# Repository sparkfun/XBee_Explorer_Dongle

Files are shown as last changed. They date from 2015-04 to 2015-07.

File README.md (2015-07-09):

SparkFun XBee Explorer Dongle
========================================

SparkFun XBee Explorer Dongle

[*SparkFun XBee Explorer Dongle (WRL-11697)*](https://www.sparkfun.com/products/11697)

With the XBee Explorer Dongle you can plug the unit directly into your USB port 
and have it act as a gateway between your computer and the XBee. It has the FT231X USB-to-serial converter IC on board. 

Repository Contents
-------------------
* **/Hardware** - All Eagle design files (.brd, .sch, .STL)
* **/Production** - Test bed files and production panel files

Documentation
--------------
* **[Hookup Guide](https://learn.sparkfun.com/tutorials/exploring-xbees-and-xctu)** - Basic hookup guide for the XBee Explorer.
* **[SparkFun Fritzing repo](https://github.com/sparkfun/Fritzing_Parts)** - Fritzing diagrams for SparkFun products.
* **[SparkFun 3D Model repo](https://github.com/sparkfun/3D_Models)** - 3D models of SparkFun products. 

Product Versions
----------------
* [WRL-11697](https://www.sparkfun.com/products/11697)- XBee Dongle with the FT232 USB to serial converter, v23. Current.
* [WRL-09819](https://www.sparkfun.com/products/retired/9819)- XBee Dongle with the FT232 USB to serial converter, v12. Retired.

Version History
---------------
* [V_2.3](https://github.com/sparkfun/XBee_Explorer_Dongle/tree/V_2.3) - GitHub files, version 2.3. Current
* [V_2.2](https://github.com/sparkfun/XBee_Explorer_Dongle/tree/V_2.2) - GitHub files, version 2.2
* [V_1.2](https://github.com/sparkfun/XBee_Explorer_Dongle/tree/V_1.2) -GitHub files, version 1.2. 

License Information
-------------------

This product is _**open source**_! 

Please review the LICENSE.md file for license information. 

If you have any questions or concerns on licensing, please contact techsupport@sparkfun.com.

Distributed as-is; no warranty is given.

- Your friends at SparkFun.

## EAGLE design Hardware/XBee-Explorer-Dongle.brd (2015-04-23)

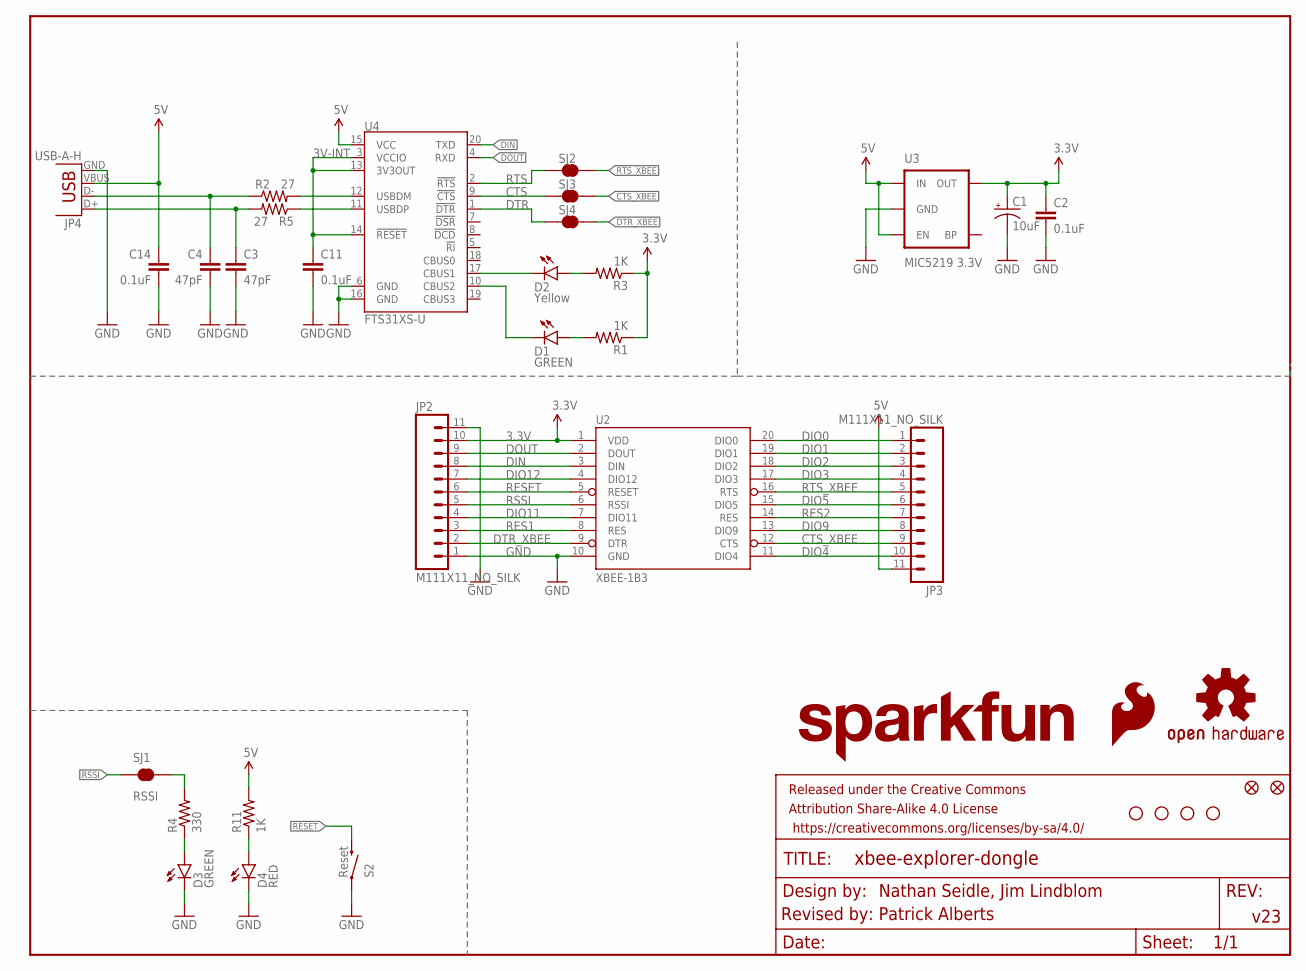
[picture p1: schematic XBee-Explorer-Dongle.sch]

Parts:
C1: 10uF; EIA3216
C2, C11, C14: 0.1uF; 0603-CAP
C3, C4: 47pF; 0603-CAP
D1, D3: GREEN; LED-0603
D2: Yellow; LED-0603
D4: RED; LED-0603
FID1, FID2: FIDUCIAL1X2; FIDUCIAL-1X2
FRAME1: FRAME-LETTER; CREATIVE_COMMONS
JP2, JP3: M111X11_NO_SILK; 1X11_NO_SILK
JP4: USB-A-H
LOGO1: SFE_LOGO_FLAME.1_INCH; SFE_LOGO_FLAME_.1
LOGO2: SFE_LOGO_NAME.2_INCH; SFE_LOGO_NAME_.2
R1, R3, R11: 1K; 0603-RES
R2, R5: 27; 0603-RES
R4: 330; 0603-RES
S2: Reset; TACTILE_SWITCH_SMD
SJ1, SJ2, SJ3, SJ4: RSSI; SJ_2S-TRACE
U2: XBEE-1B3; XBEE-SMD
U3: MIC5219 3.3V; SOT23-5
U4: FTS31XS-U; SSOP20_L
U$5, U$9, U$10, U$11: STAND-OFF
U$7: OSHW-LOGOS; OSHW-LOGO-S

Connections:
3.3V: C1.A (+), C2.1, JP2.10, R1.1, R3.1, U2.1 (VDD), U3.5 (OUT)
3V-INT: C11.1, U4.3 (VCCIO), U4.13 (3V3OUT), U4.14 (!RESET)
5V: C14.1, JP3.11, JP4.VBUS, R11.2, U3.1 (IN), U3.3 (EN), U4.15 (VCC)
CTS: SJ3.1, U4.9 (!CTS)
CTS_XBEE: JP3.9, SJ3.2, U2.12 (CTS)
DIN: JP2.8, U2.3 (DIN), U4.20 (TXD)
DIO0: JP3.1, U2.20 (DIO0)
DIO1: JP3.2, U2.19 (DIO1)
DIO2: JP3.3, U2.18 (DIO2)
DIO3: JP3.4, U2.17 (DIO3)
DIO4: JP3.10, U2.11 (DIO4)
DIO5: JP3.6, U2.15 (DIO5)
DIO9: JP3.8, U2.13 (DIO9)
DIO11: JP2.4, U2.7 (DIO11)
DIO12: JP2.7, U2.4 (DIO12)
DOUT: JP2.9, U2.2 (DOUT), U4.4 (RXD)
DTR: SJ4.1, U4.1 (!DTR)
DTR_XBEE: JP2.2, SJ4.2, U2.9 (DTR)
GND: C1.C (-), C2.2, C3.2, C4.2, C11.2, C14.2, D3.C, D4.C, JP2.1, JP2.11, JP4.GND, S2.1, U2.10 (GND), U3.2 (GND), U4.6 (GND), U4.16 (GND)
unnamed: D1.A, R1.2
unnamed: D3.A, R4.1
unnamed: C4.1, JP4.D-, R2.1
unnamed: D2.A, R3.2
unnamed: R2.2, U4.12 (USBDM)
unnamed: C3.1, JP4.D+, R5.2
unnamed: R5.1, U4.11 (USBDP)
unnamed: R4.2, SJ1.2
unnamed: D4.A, R11.1
RES1: JP2.3, U2.8 (RES)
RES2: JP3.7, U2.14 (RES)
RESET: JP2.6, S2.3 (2), U2.5 (RESET)
RSSI: JP2.5, SJ1.1, U2.6 (RSSI)
RTS: SJ2.1, U4.2 (!RTS)
RTS_XBEE: JP3.5, SJ2.2, U2.16 (RTS)
RXLED: D2.C, U4.17 (CBUS1)
TXLED: D1.C, U4.10 (CBUS2)

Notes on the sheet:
Nathan Seidle, Jim Lindblom
v23
Revised by: Patrick Alberts

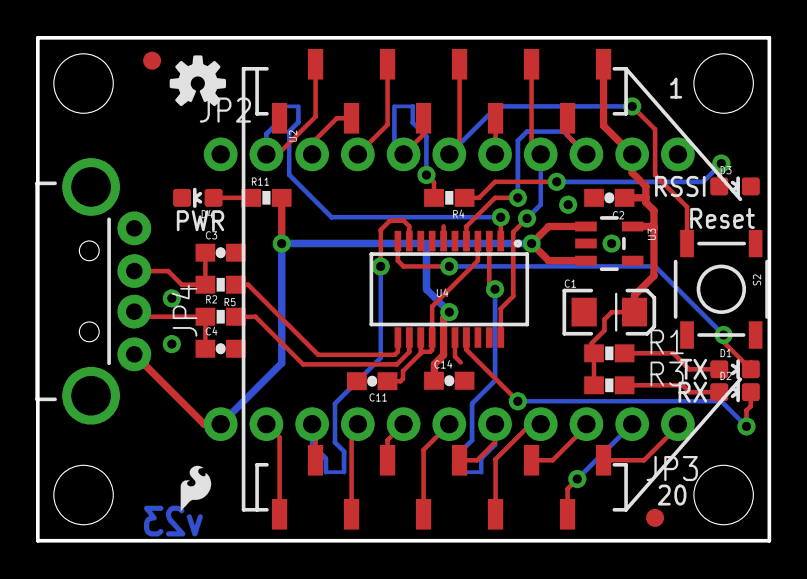
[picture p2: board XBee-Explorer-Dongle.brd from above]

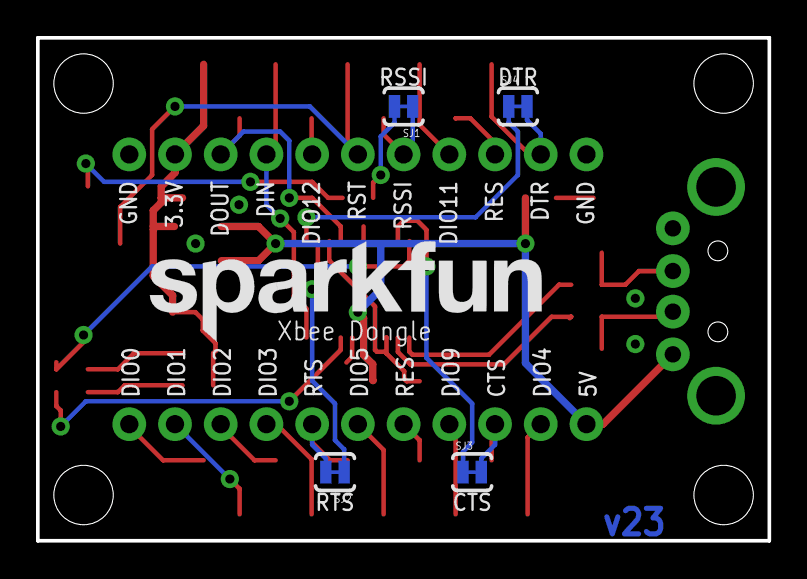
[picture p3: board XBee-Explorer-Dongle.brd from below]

Board: 2 copper layers, 40.6 x 27.9 mm, 37 parts (5 on the bottom side), 36 nets.

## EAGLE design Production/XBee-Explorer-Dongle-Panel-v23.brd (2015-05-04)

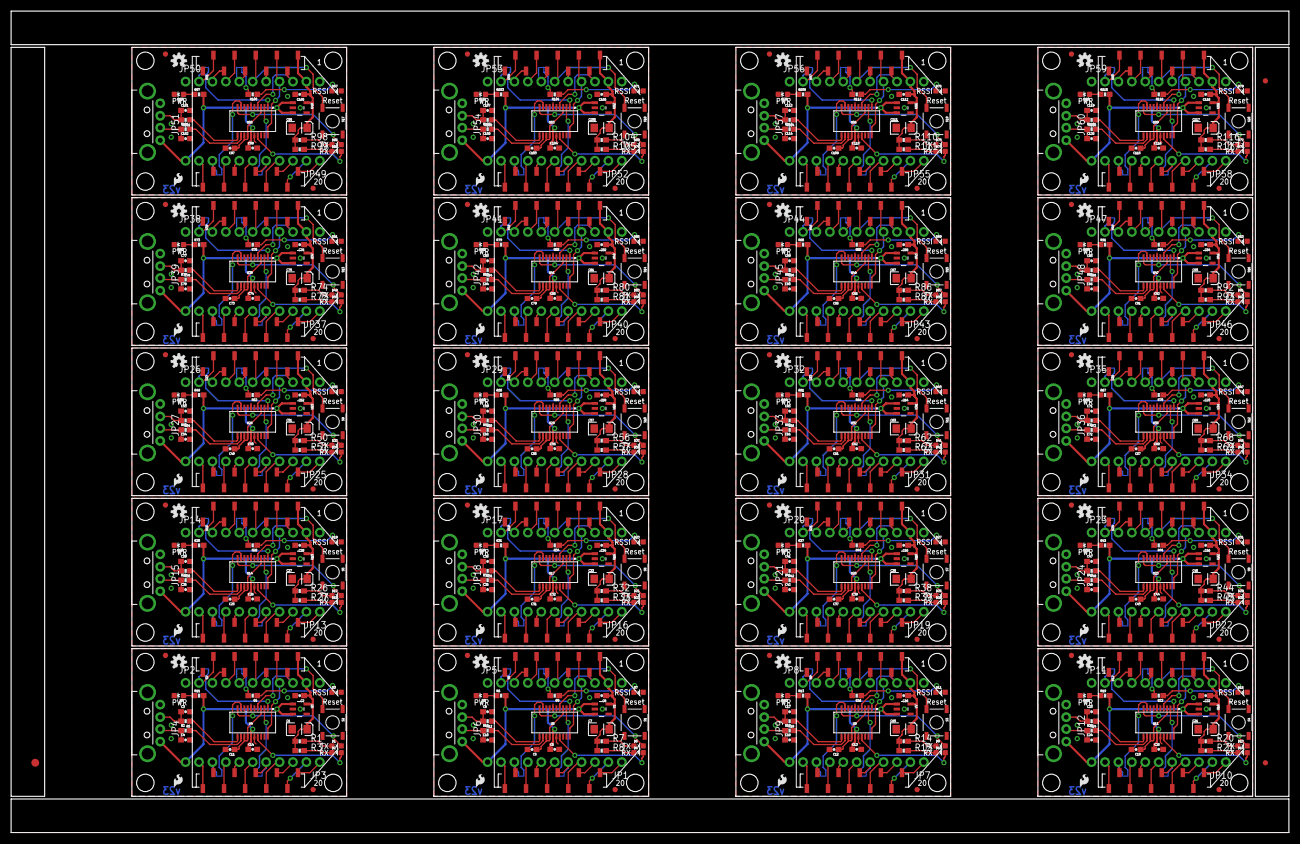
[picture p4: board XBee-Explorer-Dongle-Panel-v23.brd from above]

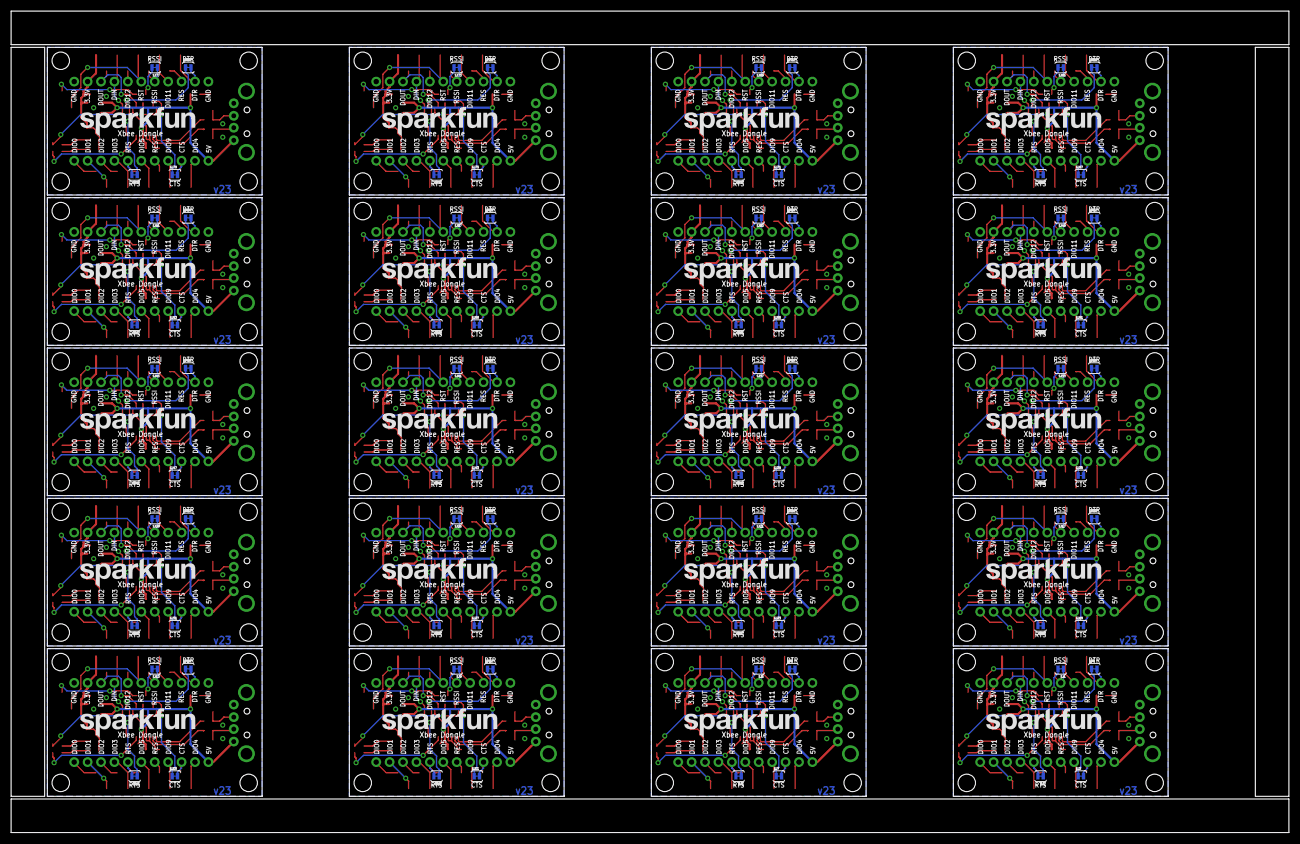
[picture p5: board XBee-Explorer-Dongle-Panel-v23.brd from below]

Board: 2 copper layers, 241.8 x 155.4 mm, 723 parts (100 on the bottom side), 720 nets.

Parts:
C1, C7, C15, C21, C27, C33, C39, C45, C51, C57, C63, C69, C75, C81, C87, C93, C99, C105, C111, C117: 10uF; EIA3216
C2, C5, C6, C8, C11, C12, C13, C14, C16, C19, C20, C22, C25, C26, C28, C31, C32, C34, C37, C38, C40, C43, C44, C46, C49, C50, C52, C55, C56, C58, C61, C62, C64, C67, C68, C70, C73, C74, C76, C79, C80, C82, C85, C86, C88, C91, C92, C94, C97, C98, C100, C103, C104, C106, C109, C110, C112, C115, C116, C118: 0.1uF; 0603-CAP
C3, C4, C9, C10, C17, C18, C23, C24, C29, C30, C35, C36, C41, C42, C47, C48, C53, C54, C59, C60, C65, C66, C71, C72, C77, C78, C83, C84, C89, C90, C95, C96, C101, C102, C107, C108, C113, C114, C119, C120: 47pF; 0603-CAP
D1, D3, D5, D7, D9, D11, D13, D15, D17, D19, D21, D23, D25, D27, D29, D31, D33, D35, D37, D39, D41, D43, D45, D47, D49, D51, D53, D55, D57, D59, D61, D63, D65, D67, D69, D71, D73, D75, D77, D79: GREEN; LED-0603
D2, D6, D10, D14, D18, D22, D26, D30, D34, D38, D42, D46, D50, D54, D58, D62, D66, D70, D74, D78: Yellow; LED-0603
D4, D8, D12, D16, D20, D24, D28, D32, D36, D40, D44, D48, D52, D56, D60, D64, D68, D72, D76, D80: RED; LED-0603
E$1: FIDUCIAL-1.5X3
E$5, E$6: FIDUCIAL-1X2
FID1, FID2, FID3, FID4, FID5, FID6, FID7, FID8, FID9, FID10, FID11, FID12, FID13, FID14, FID15, FID16, FID17, FID18, FID19, FID20, FID21, FID22, FID23, FID24, FID25, FID26, FID27, FID28, FID29, FID30, FID31, FID32, FID33, FID34, FID35, FID36, FID37, FID38, FID39, FID40: FIDUCIAL1X2; FIDUCIAL-1X2
JP1, JP2, JP3, JP5, JP7, JP8, JP10, JP11, JP13, JP14, JP16, JP17, JP19, JP20, JP22, JP23, JP25, JP26, JP28, JP29, JP31, JP32, JP34, JP35, JP37, JP38, JP40, JP41, JP43, JP44, JP46, JP47, JP49, JP50, JP52, JP53, JP55, JP56, JP58, JP59: M111X11_NO_SILK; 1X11_NO_SILK
JP4, JP6, JP9, JP12, JP15, JP18, JP21, JP24, JP27, JP30, JP33, JP36, JP39, JP42, JP45, JP48, JP51, JP54, JP57, JP60: USB-A-H
LOGO1, LOGO3, LOGO5, LOGO7, LOGO9, LOGO11, LOGO13, LOGO15, LOGO17, LOGO19, LOGO21, LOGO23, LOGO25, LOGO27, LOGO29, LOGO31, LOGO33, LOGO35, LOGO37, LOGO39: SFE_LOGO_FLAME.1_INCH; SFE_LOGO_FLAME_.1
LOGO2, LOGO4, LOGO6, LOGO8, LOGO10, LOGO12, LOGO14, LOGO16, LOGO18, LOGO20, LOGO22, LOGO24, LOGO26, LOGO28, LOGO30, LOGO32, LOGO34, LOGO36, LOGO38, LOGO40: SFE_LOGO_NAME.2_INCH; SFE_LOGO_NAME_.2
R1, R3, R6, R7, R8, R11, R13, R14, R15, R19, R20, R21, R25, R26, R27, R31, R32, R33, R37, R38, R39, R43, R44, R45, R49, R50, R51, R55, R56, R57, R61, R62, R63, R67, R68, R69, R73, R74, R75, R79, R80, R81, R85, R86, R87, R91, R92, R93, R97, R98, R99, R103, R104, R105, R109, R110, R111, R115, R116, R117: 1K; 0603-RES
R2, R5, R10, R12, R17, R18, R23, R24, R29, R30, R35, R36, R41, R42, R47, R48, R53, R54, R59, R60, R65, R66, R71, R72, R77, R78, R83, R84, R89, R90, R95, R96, R101, R102, R107, R108, R113, R114, R119, R120: 27; 0603-RES
R4, R9, R16, R22, R28, R34, R40, R46, R52, R58, R64, R70, R76, R82, R88, R94, R100, R106, R112, R118: 330; 0603-RES
S1, S2, S3, S4, S5, S6, S7, S8, S9, S10, S11, S12, S13, S14, S15, S16, S17, S18, S19, S20: Reset; TACTILE_SWITCH_SMD
SJ1, SJ2, SJ3, SJ4, SJ5, SJ6, SJ7, SJ8, SJ9, SJ10, SJ11, SJ12, SJ13, SJ14, SJ15, SJ16, SJ17, SJ18, SJ19, SJ20, SJ21, SJ22, SJ23, SJ24, SJ25, SJ26, SJ27, SJ28, SJ29, SJ30, SJ31, SJ32, SJ33, SJ34, SJ35, SJ36, SJ37, SJ38, SJ39, SJ40, SJ41, SJ42, SJ43, SJ44, SJ45, SJ46, SJ47, SJ48, SJ49, SJ50, SJ51, SJ52, SJ53, SJ54, SJ55, SJ56, SJ57, SJ58, SJ59, SJ60, SJ61, SJ62, SJ63, SJ64, SJ65, SJ66, SJ67, SJ68, SJ69, SJ70, SJ71, SJ72, SJ73, SJ74, SJ75, SJ76, SJ77, SJ78, SJ79, SJ80: RSSI; SJ_2S-TRACE
U1, U3, U7, U10, U13, U16, U19, U22, U25, U28, U31, U34, U37, U40, U43, U46, U49, U52, U55, U58: MIC5219 3.3V; SOT23-5
U2, U6, U9, U12, U15, U18, U21, U24, U27, U30, U33, U36, U39, U42, U45, U48, U51, U54, U57, U60: XBEE-1B3; XBEE-SMD
U4, U5, U8, U11, U14, U17, U20, U23, U26, U29, U32, U35, U38, U41, U44, U47, U50, U53, U56, U59: FTS31XS-U; SSOP20_L
U$1, U$2, U$3, U$4, U$5, U$8, U$9, U$10, U$11, U$12, U$13, U$14, U$16, U$17, U$18, U$19, U$21, U$22, U$23, U$24, U$26, U$27, U$28, U$29, U$31, U$32, U$33, U$34, U$36, U$37, U$38, U$39, U$41, U$42, U$43, U$44, U$46, U$47, U$48, U$49, U$51, U$52, U$53, U$54, U$56, U$57, U$58, U$59, U$61, U$62, U$63, U$64, U$66, U$67, U$68, U$69, U$71, U$72, U$73, U$74, U$76, U$77, U$78, U$79, U$81, U$82, U$83, U$84, U$86, U$87, U$88, U$89, U$91, U$92, U$93, U$94, U$96, U$97, U$98, U$99: STAND-OFF
U$6, U$7, U$15, U$20, U$25, U$30, U$35, U$40, U$45, U$50, U$55, U$60, U$65, U$70, U$75, U$80, U$85, U$90, U$95, U$100: OSHW-LOGOS; OSHW-LOGO-S

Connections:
3.3V: C1.A, C2.1, JP2.10, R1.1, R3.1, U2.1, U3.5
3.3V1: C7.A, C8.1, JP5.10, R7.1, R8.1, U1.5, U6.1
3.3V2: C15.A, C16.1, JP8.10, R14.1, R15.1, U7.5, U9.1
3.3V3: C21.A, C22.1, JP11.10, R20.1, R21.1, U10.5, U12.1
3.3V4: C27.A, C28.1, JP14.10, R26.1, R27.1, U13.5, U15.1
3.3V5: C33.A, C34.1, JP17.10, R32.1, R33.1, U16.5, U18.1
3.3V6: C39.A, C40.1, JP20.10, R38.1, R39.1, U19.5, U21.1
3.3V7: C45.A, C46.1, JP23.10, R44.1, R45.1, U22.5, U24.1
3.3V8: C51.A, C52.1, JP26.10, R50.1, R51.1, U25.5, U27.1
3.3V9: C57.A, C58.1, JP29.10, R56.1, R57.1, U28.5, U30.1
3.3V10: C63.A, C64.1, JP32.10, R62.1, R63.1, U31.5, U33.1
3.3V11: C69.A, C70.1, JP35.10, R68.1, R69.1, U34.5, U36.1
3.3V12: C75.A, C76.1, JP38.10, R74.1, R75.1, U37.5, U39.1
3.3V13: C81.A, C82.1, JP41.10, R80.1, R81.1, U40.5, U42.1
3.3V14: C87.A, C88.1, JP44.10, R86.1, R87.1, U43.5, U45.1
3.3V15: C93.A, C94.1, JP47.10, R92.1, R93.1, U46.5, U48.1
3.3V16: C99.A, C100.1, JP50.10, R98.1, R99.1, U49.5, U51.1
3.3V17: C105.A, C106.1, JP53.10, R104.1, R105.1, U52.5, U54.1
3.3V18: C111.A, C112.1, JP56.10, R110.1, R111.1, U55.5, U57.1
3.3V19: C117.A, C118.1, JP59.10, R116.1, R117.1, U58.5, U60.1
3V-INT: C11.1, U4.3, U4.13, U4.14
3V-INT1: C5.1, U5.3, U5.13, U5.14
3V-INT2: C12.1, U8.3, U8.13, U8.14
3V-INT3: C19.1, U11.3, U11.13, U11.14
3V-INT4: C25.1, U14.3, U14.13, U14.14
3V-INT5: C31.1, U17.3, U17.13, U17.14
3V-INT6: C37.1, U20.3, U20.13, U20.14
3V-INT7: C43.1, U23.3, U23.13, U23.14
3V-INT8: C49.1, U26.3, U26.13, U26.14
3V-INT9: C55.1, U29.3, U29.13, U29.14
3V-INT10: C61.1, U32.3, U32.13, U32.14
3V-INT11: C67.1, U35.3, U35.13, U35.14
3V-INT12: C73.1, U38.3, U38.13, U38.14
3V-INT13: C79.1, U41.3, U41.13, U41.14
3V-INT14: C85.1, U44.3, U44.13, U44.14
3V-INT15: C91.1, U47.3, U47.13, U47.14
3V-INT16: C97.1, U50.3, U50.13, U50.14
3V-INT17: C103.1, U53.3, U53.13, U53.14
3V-INT18: C109.1, U56.3, U56.13, U56.14
3V-INT19: C115.1, U59.3, U59.13, U59.14
5V: C14.1, JP3.11, JP4.VBUS, R11.2, U3.1, U3.3, U4.15
5V1: C6.1, JP1.11, JP6.VBUS, R6.2, U1.1, U1.3, U5.15
5V2: C13.1, JP7.11, JP9.VBUS, R13.2, U7.1, U7.3, U8.15
5V3: C20.1, JP10.11, JP12.VBUS, R19.2, U10.1, U10.3, U11.15
5V4: C26.1, JP13.11, JP15.VBUS, R25.2, U13.1, U13.3, U14.15
5V5: C32.1, JP16.11, JP18.VBUS, R31.2, U16.1, U16.3, U17.15
5V6: C38.1, JP19.11, JP21.VBUS, R37.2, U19.1, U19.3, U20.15
5V7: C44.1, JP22.11, JP24.VBUS, R43.2, U22.1, U22.3, U23.15
5V8: C50.1, JP25.11, JP27.VBUS, R49.2, U25.1, U25.3, U26.15
5V9: C56.1, JP28.11, JP30.VBUS, R55.2, U28.1, U28.3, U29.15
5V10: C62.1, JP31.11, JP33.VBUS, R61.2, U31.1, U31.3, U32.15
5V11: C68.1, JP34.11, JP36.VBUS, R67.2, U34.1, U34.3, U35.15
5V12: C74.1, JP37.11, JP39.VBUS, R73.2, U37.1, U37.3, U38.15
5V13: C80.1, JP40.11, JP42.VBUS, R79.2, U40.1, U40.3, U41.15
5V14: C86.1, JP43.11, JP45.VBUS, R85.2, U43.1, U43.3, U44.15
5V15: C92.1, JP46.11, JP48.VBUS, R91.2, U46.1, U46.3, U47.15
5V16: C98.1, JP49.11, JP51.VBUS, R97.2, U49.1, U49.3, U50.15
5V17: C104.1, JP52.11, JP54.VBUS, R103.2, U52.1, U52.3, U53.15
5V18: C110.1, JP55.11, JP57.VBUS, R109.2, U55.1, U55.3, U56.15
5V19: C116.1, JP58.11, JP60.VBUS, R115.2, U58.1, U58.3, U59.15
CTS: SJ3.1, U4.9
CTS1: SJ7.1, U5.9
CTS2: SJ11.1, U8.9
CTS3: SJ15.1, U11.9
CTS4: SJ19.1, U14.9
CTS5: SJ23.1, U17.9
CTS6: SJ27.1, U20.9
CTS7: SJ31.1, U23.9
CTS8: SJ35.1, U26.9
CTS9: SJ39.1, U29.9
CTS10: SJ43.1, U32.9
CTS11: SJ47.1, U35.9
CTS12: SJ51.1, U38.9
CTS13: SJ55.1, U41.9
CTS14: SJ59.1, U44.9
CTS15: SJ63.1, U47.9
CTS16: SJ67.1, U50.9
CTS17: SJ71.1, U53.9
CTS18: SJ75.1, U56.9
CTS19: SJ79.1, U59.9
CTS_XBEE: JP3.9, SJ3.2, U2.12
CTS_XBEE1: JP1.9, SJ7.2, U6.12
CTS_XBEE2: JP7.9, SJ11.2, U9.12
CTS_XBEE3: JP10.9, SJ15.2, U12.12
CTS_XBEE4: JP13.9, SJ19.2, U15.12
CTS_XBEE5: JP16.9, SJ23.2, U18.12
CTS_XBEE6: JP19.9, SJ27.2, U21.12
CTS_XBEE7: JP22.9, SJ31.2, U24.12
CTS_XBEE8: JP25.9, SJ35.2, U27.12
CTS_XBEE9: JP28.9, SJ39.2, U30.12
CTS_XBEE10: JP31.9, SJ43.2, U33.12
CTS_XBEE11: JP34.9, SJ47.2, U36.12
CTS_XBEE12: JP37.9, SJ51.2, U39.12
CTS_XBEE13: JP40.9, SJ55.2, U42.12
CTS_XBEE14: JP43.9, SJ59.2, U45.12
CTS_XBEE15: JP46.9, SJ63.2, U48.12
CTS_XBEE16: JP49.9, SJ67.2, U51.12
CTS_XBEE17: JP52.9, SJ71.2, U54.12
CTS_XBEE18: JP55.9, SJ75.2, U57.12
CTS_XBEE19: JP58.9, SJ79.2, U60.12
DIN: JP2.8, U2.3, U4.20
DIN1: JP5.8, U5.20, U6.3
DIN2: JP8.8, U8.20, U9.3
DIN3: JP11.8, U11.20, U12.3
DIN4: JP14.8, U14.20, U15.3
DIN5: JP17.8, U17.20, U18.3
DIN6: JP20.8, U20.20, U21.3
DIN7: JP23.8, U23.20, U24.3
DIN8: JP26.8, U26.20, U27.3
DIN9: JP29.8, U29.20, U30.3
DIN10: JP32.8, U32.20, U33.3
DIN11: JP35.8, U35.20, U36.3
DIN12: JP38.8, U38.20, U39.3
DIN13: JP41.8, U41.20, U42.3
DIN14: JP44.8, U44.20, U45.3
DIN15: JP47.8, U47.20, U48.3
DIN16: JP50.8, U50.20, U51.3
DIN17: JP53.8, U53.20, U54.3
DIN18: JP56.8, U56.20, U57.3
DIN19: JP59.8, U59.20, U60.3
DIO0: JP3.1, U2.20
DIO1: JP3.2, U2.19
DIO2: JP3.3, U2.18
DIO3: JP3.4, U2.17
DIO4: JP3.10, U2.11
DIO5: JP3.6, U2.15
DIO6: JP1.10, U6.11
DIO7: JP1.8, U6.13
DIO8: JP1.6, U6.15
DIO9: JP3.8, U2.13
DIO10: JP1.4, U6.17
DIO11: JP2.4, U2.7
DIO12: JP2.7, U2.4
DIO13: JP1.3, U6.18
DIO14: JP1.2, U6.19
DIO15: JP1.1, U6.20
DIO16: JP5.4, U6.7
DIO17: JP5.7, U6.4
DIO18: JP7.10, U9.11
DIO19: JP7.8, U9.13
DIO20: JP7.6, U9.15
DIO21: JP7.4, U9.17
DIO22: JP7.3, U9.18
DIO23: JP7.2, U9.19
DIO24: JP7.1, U9.20
DIO25: JP8.4, U9.7
DIO26: JP8.7, U9.4
DIO27: JP10.10, U12.11
DIO28: JP10.8, U12.13
DIO29: JP10.6, U12.15
DIO30: JP10.4, U12.17
DIO31: JP10.3, U12.18
DIO32: JP10.2, U12.19
DIO33: JP10.1, U12.20
DIO34: JP11.4, U12.7
DIO35: JP11.7, U12.4
DIO36: JP13.10, U15.11
DIO37: JP13.8, U15.13
DIO38: JP13.6, U15.15
DIO39: JP13.4, U15.17
DIO40: JP13.3, U15.18
DIO41: JP13.2, U15.19
DIO42: JP13.1, U15.20
DIO43: JP14.4, U15.7
DIO44: JP14.7, U15.4
DIO45: JP16.10, U18.11
DIO46: JP16.8, U18.13
DIO47: JP16.6, U18.15
DIO48: JP16.4, U18.17
DIO49: JP16.3, U18.18
DIO50: JP16.2, U18.19
DIO51: JP16.1, U18.20
DIO52: JP17.4, U18.7
DIO53: JP17.7, U18.4
DIO54: JP19.10, U21.11
DIO55: JP19.8, U21.13
DIO56: JP19.6, U21.15
DIO57: JP19.4, U21.17
DIO58: JP19.3, U21.18
DIO59: JP19.2, U21.19
DIO60: JP19.1, U21.20
DIO61: JP20.4, U21.7
DIO62: JP20.7, U21.4
DIO63: JP22.10, U24.11
DIO64: JP22.8, U24.13
DIO65: JP22.6, U24.15
DIO66: JP22.4, U24.17
DIO67: JP22.3, U24.18
DIO68: JP22.2, U24.19
DIO69: JP22.1, U24.20
DIO70: JP23.4, U24.7
DIO71: JP23.7, U24.4
DIO72: JP25.10, U27.11
DIO73: JP25.8, U27.13
DIO74: JP25.6, U27.15
DIO75: JP25.4, U27.17
DIO76: JP25.3, U27.18
DIO77: JP25.2, U27.19
DIO78: JP25.1, U27.20
DIO79: JP26.4, U27.7
DIO80: JP26.7, U27.4
DIO81: JP28.10, U30.11
DIO82: JP28.8, U30.13
DIO83: JP28.6, U30.15
DIO84: JP28.4, U30.17
DIO85: JP28.3, U30.18
DIO86: JP28.2, U30.19
DIO87: JP28.1, U30.20
DIO88: JP29.4, U30.7
DIO89: JP29.7, U30.4
DIO90: JP31.10, U33.11
DIO91: JP31.8, U33.13
DIO92: JP31.6, U33.15
DIO93: JP31.4, U33.17
DIO94: JP31.3, U33.18
DIO95: JP31.2, U33.19
DIO96: JP31.1, U33.20
DIO97: JP32.4, U33.7
DIO98: JP32.7, U33.4
DIO99: JP34.10, U36.11
DIO100: JP34.8, U36.13
DIO101: JP34.6, U36.15
DIO102: JP34.4, U36.17
DIO103: JP34.3, U36.18
DIO104: JP34.2, U36.19
DIO105: JP34.1, U36.20
DIO106: JP35.4, U36.7
DIO107: JP35.7, U36.4
DIO108: JP37.10, U39.11
DIO109: JP37.8, U39.13
DIO110: JP37.6, U39.15
DIO111: JP37.4, U39.17
DIO112: JP37.3, U39.18
DIO113: JP37.2, U39.19
DIO114: JP37.1, U39.20
DIO115: JP38.4, U39.7
DIO116: JP38.7, U39.4
DIO117: JP40.10, U42.11
DIO118: JP40.8, U42.13
DIO119: JP40.6, U42.15
DIO120: JP40.4, U42.17
DIO121: JP40.3, U42.18
DIO122: JP40.2, U42.19
DIO123: JP40.1, U42.20
DIO124: JP41.4, U42.7
DIO125: JP41.7, U42.4
DIO126: JP43.10, U45.11
DIO127: JP43.8, U45.13
DIO128: JP43.6, U45.15
DIO129: JP43.4, U45.17
DIO130: JP43.3, U45.18
DIO131: JP43.2, U45.19
DIO132: JP43.1, U45.20
DIO133: JP44.4, U45.7
DIO134: JP44.7, U45.4
DIO135: JP46.10, U48.11
DIO136: JP46.8, U48.13
DIO137: JP46.6, U48.15
DIO138: JP46.4, U48.17
DIO139: JP46.3, U48.18
DIO140: JP46.2, U48.19
DIO141: JP46.1, U48.20
DIO142: JP47.4, U48.7
DIO143: JP47.7, U48.4
DIO144: JP49.10, U51.11
DIO145: JP49.8, U51.13
DIO146: JP49.6, U51.15
DIO147: JP49.4, U51.17
DIO148: JP49.3, U51.18
DIO149: JP49.2, U51.19
DIO150: JP49.1, U51.20
DIO151: JP50.4, U51.7
DIO152: JP50.7, U51.4
DIO153: JP52.10, U54.11
DIO154: JP52.8, U54.13
DIO155: JP52.6, U54.15
DIO156: JP52.4, U54.17
DIO157: JP52.3, U54.18
DIO158: JP52.2, U54.19
DIO159: JP52.1, U54.20
DIO160: JP53.4, U54.7
DIO161: JP53.7, U54.4
DIO162: JP55.10, U57.11
DIO163: JP55.8, U57.13
DIO164: JP55.6, U57.15
DIO165: JP55.4, U57.17
DIO166: JP55.3, U57.18
DIO167: JP55.2, U57.19
DIO168: JP55.1, U57.20
DIO169: JP56.4, U57.7
DIO170: JP56.7, U57.4
DIO171: JP58.10, U60.11
DIO172: JP58.8, U60.13
DIO173: JP58.6, U60.15
DIO174: JP58.4, U60.17
DIO175: JP58.3, U60.18
DIO176: JP58.2, U60.19
DIO177: JP58.1, U60.20
DIO178: JP59.4, U60.7
DIO179: JP59.7, U60.4
DOUT: JP2.9, U2.2, U4.4
DOUT1: JP5.9, U5.4, U6.2
DOUT2: JP8.9, U8.4, U9.2
DOUT3: JP11.9, U11.4, U12.2
DOUT4: JP14.9, U14.4, U15.2
DOUT5: JP17.9, U17.4, U18.2
DOUT6: JP20.9, U20.4, U21.2
DOUT7: JP23.9, U23.4, U24.2
DOUT8: JP26.9, U26.4, U27.2
DOUT9: JP29.9, U29.4, U30.2
DOUT10: JP32.9, U32.4, U33.2
DOUT11: JP35.9, U35.4, U36.2
DOUT12: JP38.9, U38.4, U39.2
DOUT13: JP41.9, U41.4, U42.2
DOUT14: JP44.9, U44.4, U45.2
DOUT15: JP47.9, U47.4, U48.2
DOUT16: JP50.9, U50.4, U51.2
DOUT17: JP53.9, U53.4, U54.2
DOUT18: JP56.9, U56.4, U57.2
DOUT19: JP59.9, U59.4, U60.2
DTR: SJ4.1, U4.1
DTR1: SJ8.1, U5.1
DTR2: SJ12.1, U8.1
DTR3: SJ16.1, U11.1
DTR4: SJ20.1, U14.1
DTR5: SJ24.1, U17.1
DTR6: SJ28.1, U20.1
DTR7: SJ32.1, U23.1
DTR8: SJ36.1, U26.1
DTR9: SJ40.1, U29.1
DTR10: SJ44.1, U32.1
DTR11: SJ48.1, U35.1
DTR12: SJ52.1, U38.1
DTR13: SJ56.1, U41.1
DTR14: SJ60.1, U44.1
DTR15: SJ64.1, U47.1
DTR16: SJ68.1, U50.1
DTR17: SJ72.1, U53.1
DTR18: SJ76.1, U56.1
DTR19: SJ80.1, U59.1
DTR_XBEE: JP2.2, SJ4.2, U2.9
DTR_XBEE1: JP5.2, SJ8.2, U6.9
DTR_XBEE2: JP8.2, SJ12.2, U9.9
DTR_XBEE3: JP11.2, SJ16.2, U12.9
DTR_XBEE4: JP14.2, SJ20.2, U15.9
DTR_XBEE5: JP17.2, SJ24.2, U18.9
DTR_XBEE6: JP20.2, SJ28.2, U21.9
DTR_XBEE7: JP23.2, SJ32.2, U24.9
DTR_XBEE8: JP26.2, SJ36.2, U27.9
DTR_XBEE9: JP29.2, SJ40.2, U30.9
DTR_XBEE10: JP32.2, SJ44.2, U33.9
DTR_XBEE11: JP35.2, SJ48.2, U36.9
DTR_XBEE12: JP38.2, SJ52.2, U39.9
DTR_XBEE13: JP41.2, SJ56.2, U42.9
DTR_XBEE14: JP44.2, SJ60.2, U45.9
DTR_XBEE15: JP47.2, SJ64.2, U48.9
DTR_XBEE16: JP50.2, SJ68.2, U51.9
DTR_XBEE17: JP53.2, SJ72.2, U54.9
DTR_XBEE18: JP56.2, SJ76.2, U57.9
DTR_XBEE19: JP59.2, SJ80.2, U60.9
GND: C1.C, C2.2, C3.2, C4.2, C11.2, C14.2, D3.C, D4.C, JP2.1, JP2.11, JP4.GND, S2.1, U2.10, U3.2, U4.6, U4.16
GND1: C5.2, C6.2, C7.C, C8.2, C9.2, C10.2, D7.C, D8.C, JP5.1, JP5.11, JP6.GND, S1.1, U1.2, U5.6, U5.16, U6.10
GND2: C12.2, C13.2, C15.C, C16.2, C17.2, C18.2, D11.C, D12.C, JP8.1, JP8.11, JP9.GND, S3.1, U7.2, U8.6, U8.16, U9.10
GND3: C19.2, C20.2, C21.C, C22.2, C23.2, C24.2, D15.C, D16.C, JP11.1, JP11.11, JP12.GND, S4.1, U10.2, U11.6, U11.16, U12.10
GND4: C25.2, C26.2, C27.C, C28.2, C29.2, C30.2, D19.C, D20.C, JP14.1, JP14.11, JP15.GND, S5.1, U13.2, U14.6, U14.16, U15.10
GND5: C31.2, C32.2, C33.C, C34.2, C35.2, C36.2, D23.C, D24.C, JP17.1, JP17.11, JP18.GND, S6.1, U16.2, U17.6, U17.16, U18.10
GND6: C37.2, C38.2, C39.C, C40.2, C41.2, C42.2, D27.C, D28.C, JP20.1, JP20.11, JP21.GND, S7.1, U19.2, U20.6, U20.16, U21.10
GND7: C43.2, C44.2, C45.C, C46.2, C47.2, C48.2, D31.C, D32.C, JP23.1, JP23.11, JP24.GND, S8.1, U22.2, U23.6, U23.16, U24.10
GND8: C49.2, C50.2, C51.C, C52.2, C53.2, C54.2, D35.C, D36.C, JP26.1, JP26.11, JP27.GND, S9.1, U25.2, U26.6, U26.16, U27.10
GND9: C55.2, C56.2, C57.C, C58.2, C59.2, C60.2, D39.C, D40.C, JP29.1, JP29.11, JP30.GND, S10.1, U28.2, U29.6, U29.16, U30.10
GND10: C61.2, C62.2, C63.C, C64.2, C65.2, C66.2, D43.C, D44.C, JP32.1, JP32.11, JP33.GND, S11.1, U31.2, U32.6, U32.16, U33.10
GND11: C67.2, C68.2, C69.C, C70.2, C71.2, C72.2, D47.C, D48.C, JP35.1, JP35.11, JP36.GND, S12.1, U34.2, U35.6, U35.16, U36.10
GND12: C73.2, C74.2, C75.C, C76.2, C77.2, C78.2, D51.C, D52.C, JP38.1, JP38.11, JP39.GND, S13.1, U37.2, U38.6, U38.16, U39.10
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

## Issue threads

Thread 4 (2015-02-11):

Trace fix needed (N$5)

ericorosel, 2015-02-11:
-I think this trace was probably this way on the previous design. The trace isn't exactly straight, I figure while we are rev'ing we may as well fix this too. (see pic)

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

Closed 2015-02-20.

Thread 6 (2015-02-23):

5V trace needs re-sizing

ericorosel, 2015-02-23:
There is a section of the "5V' trace that is .01" when the rest of that trace is .016". I think the whole trace should be 0.16".

The stretch of thin trace is between the USB_VBUS pin and the next via.

ericorosel, 2015-03-03:
5V still needs fixing:
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

and...
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

Closed 2015-03-03.

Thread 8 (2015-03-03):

3.3V trace width adjustment needed

ericorosel, 2015-03-03:
From the 3.3V through-hole to to the XBee header the 3.3V line is .01" and from the through-hole to the vreg the width is .016". I would increase the width of the former to match the width of the latter.

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

Closed 2015-03-03.

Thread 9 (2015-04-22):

Silk issues

ericorosel, 2015-04-22:
(1) "XBee Dongle" silk is overlapping some of the XBee through-hole silk labels

(2) Some of the text on the board is proportional font; should be vector font.

PatrickAlberts, 2015-04-23:
Issues fixed.  New files are uploaded.

ericorosel, 2015-04-23:
Verified, thanks Patrick!

Closed 2015-04-23.

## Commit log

2015-01-21 Deleting USB files
    [XBee-Explorer-GiantPanel-v21.brd, XBee-Explorer.brd, XBee-Explorer.sch]
2015-01-21 Adding README with product information
    [XBee-Explorer-Dongle-GiantPanel-v22.brd, XBee-Explorer-Dongle.brd, XBee-Explorer-Dongle.sch]
2015-02-11 Upd to usb pth, 0603, sch changes
    [XBee-Explorer-Dongle.brd, XBee-Explorer-Dongle.sch]
2015-02-21 QC checklist items complete.
    [XBee-Explorer-Dongle.brd, XBee-Explorer-Dongle.sch]
2015-02-25 Fixed qc issues.
    [XBee-Explorer-Dongle.brd]
2015-03-03 FIxed qc issues
    [XBee-Explorer-Dongle.brd]
2015-03-23 Fixed USB alignment issue.
    [XBee-Explorer-Dongle.brd, XBee-Explorer-Dongle.sch]
2015-04-13 Moved Sch item.
    [XBee-Explorer-Dongle.brd]
2015-04-23 Changed font to Vector, and re arranged SPK logo
    [XBee-Explorer-Dongle.brd, XBee-Explorer-Dongle.sch]
2015-05-04 created new v23 panel
    [XBee-Explorer-Dongle-GiantPanel-v22.brd, XBee-Explorer-Dongle-Panel-v23.brd]

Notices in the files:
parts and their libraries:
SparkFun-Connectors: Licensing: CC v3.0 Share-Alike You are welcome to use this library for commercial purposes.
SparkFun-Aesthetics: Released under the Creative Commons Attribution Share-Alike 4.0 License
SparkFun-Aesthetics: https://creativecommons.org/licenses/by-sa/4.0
